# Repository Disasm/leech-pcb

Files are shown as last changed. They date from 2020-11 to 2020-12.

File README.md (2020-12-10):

# Leech

An extension board with iCE40UP5k for the STM32F411 "Black Pill" board.

This project is based on the [icepill] project by [Adam Greig].
Some of the footprints were also taken from the icepill project.

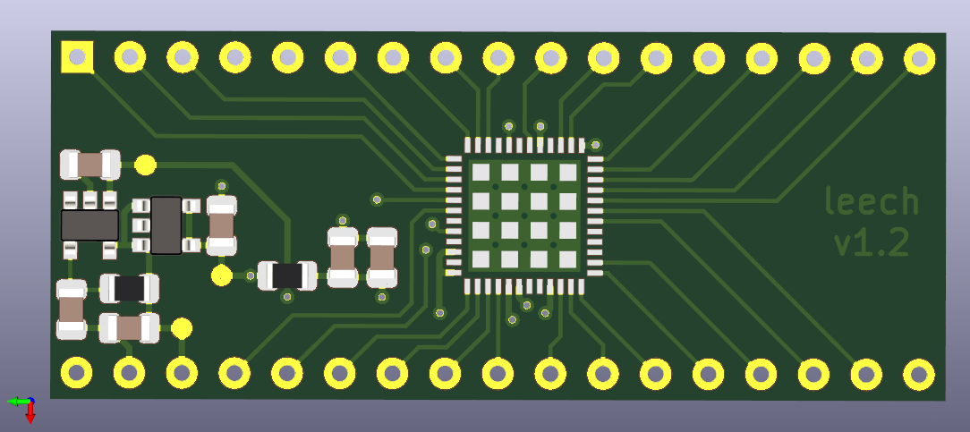
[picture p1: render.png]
PCB render

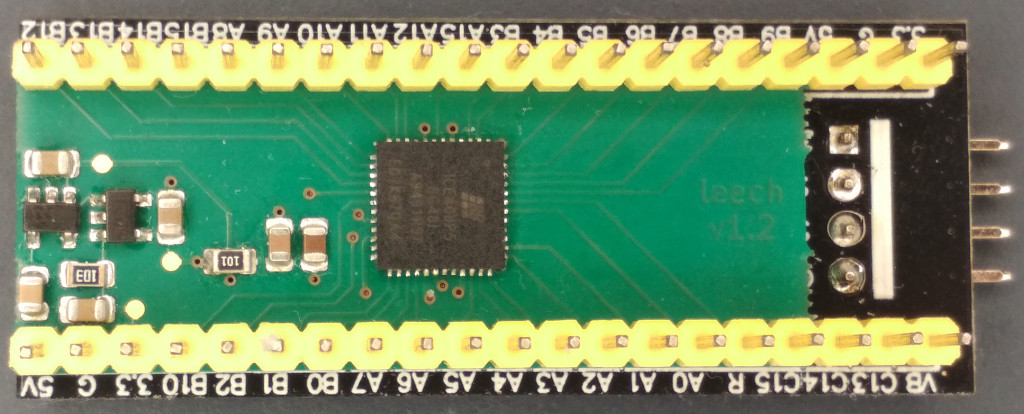
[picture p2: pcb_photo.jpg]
PCB photo


| iCE40  | STM32 | Notes
|---|---|---
| 16 | PB12  | SPI SS
| 15 | PB13  | SPI SCK
| 14 | PB14  | SPI MISO
| 17 | PB15  | SPI MOSI
| 20 | PA8 | Clock for iCE40 provided by MCO
| 13 | PA9 |
| 12 | PA10  |
| 11 | PA11  |
| 10 | PA12  |
| 6 | PA15  |
| 3 | PB3 |
| 2 | PB4 |
| 48 | PB5 |
| 47 | PB6 |
| 46 | PB7 |
| 45 | PB8 |
| 44 | PB9 |
| | |
| 18 | PB10  | Used for IRQ
| CRESET | PB2 | This line is pulled down by the main board
| 25 | PB1 |
| 26 | PB0 |
| 27 | PA7 |
| 28 | PA6 |
| 34 | PA5 |
| 35 | PA4 |
| 36 | PA3 |
| 37 | PA2 |
| 38 | PA1 |
| 42 | PA0 | Connected to a button on the main board
| 43 | RESET |

Firmware and gateware: https://github.com/Disasm/leech-fw

This schematic and PCB design are licensed under the
Creative Commons [CC0 public domain dedication].
It is provided with no warranty.

[icepill]: https://github.com/adamgreig/icepill
[Adam Greig]: https://github.com/adamgreig
[CC0 public domain dedication]: https://creativecommons.org/publicdomain/zero/1.0/

## Revision History

### 1.2: 2020-11-13

* First version.
* Errata:
    * Drill diameter of 2.54mm connector pads is too small.

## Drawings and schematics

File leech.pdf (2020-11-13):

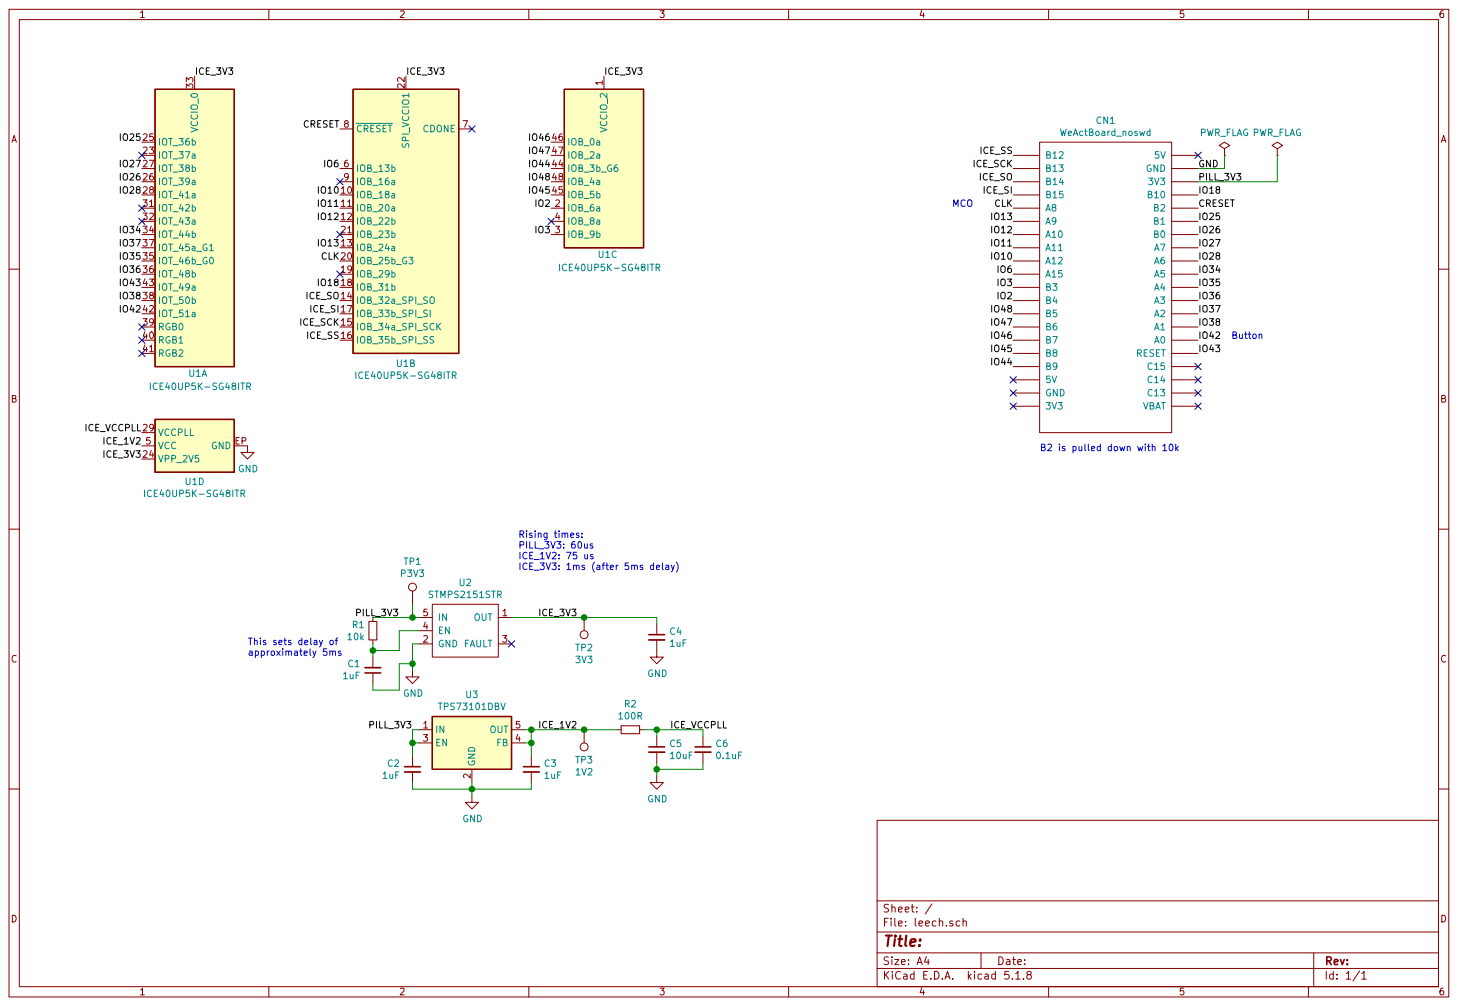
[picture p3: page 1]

IO10 This sets delay of

B2 is pulled down with 10k

Id: 1/1 Title: File: leech.sch Sheet: / C1

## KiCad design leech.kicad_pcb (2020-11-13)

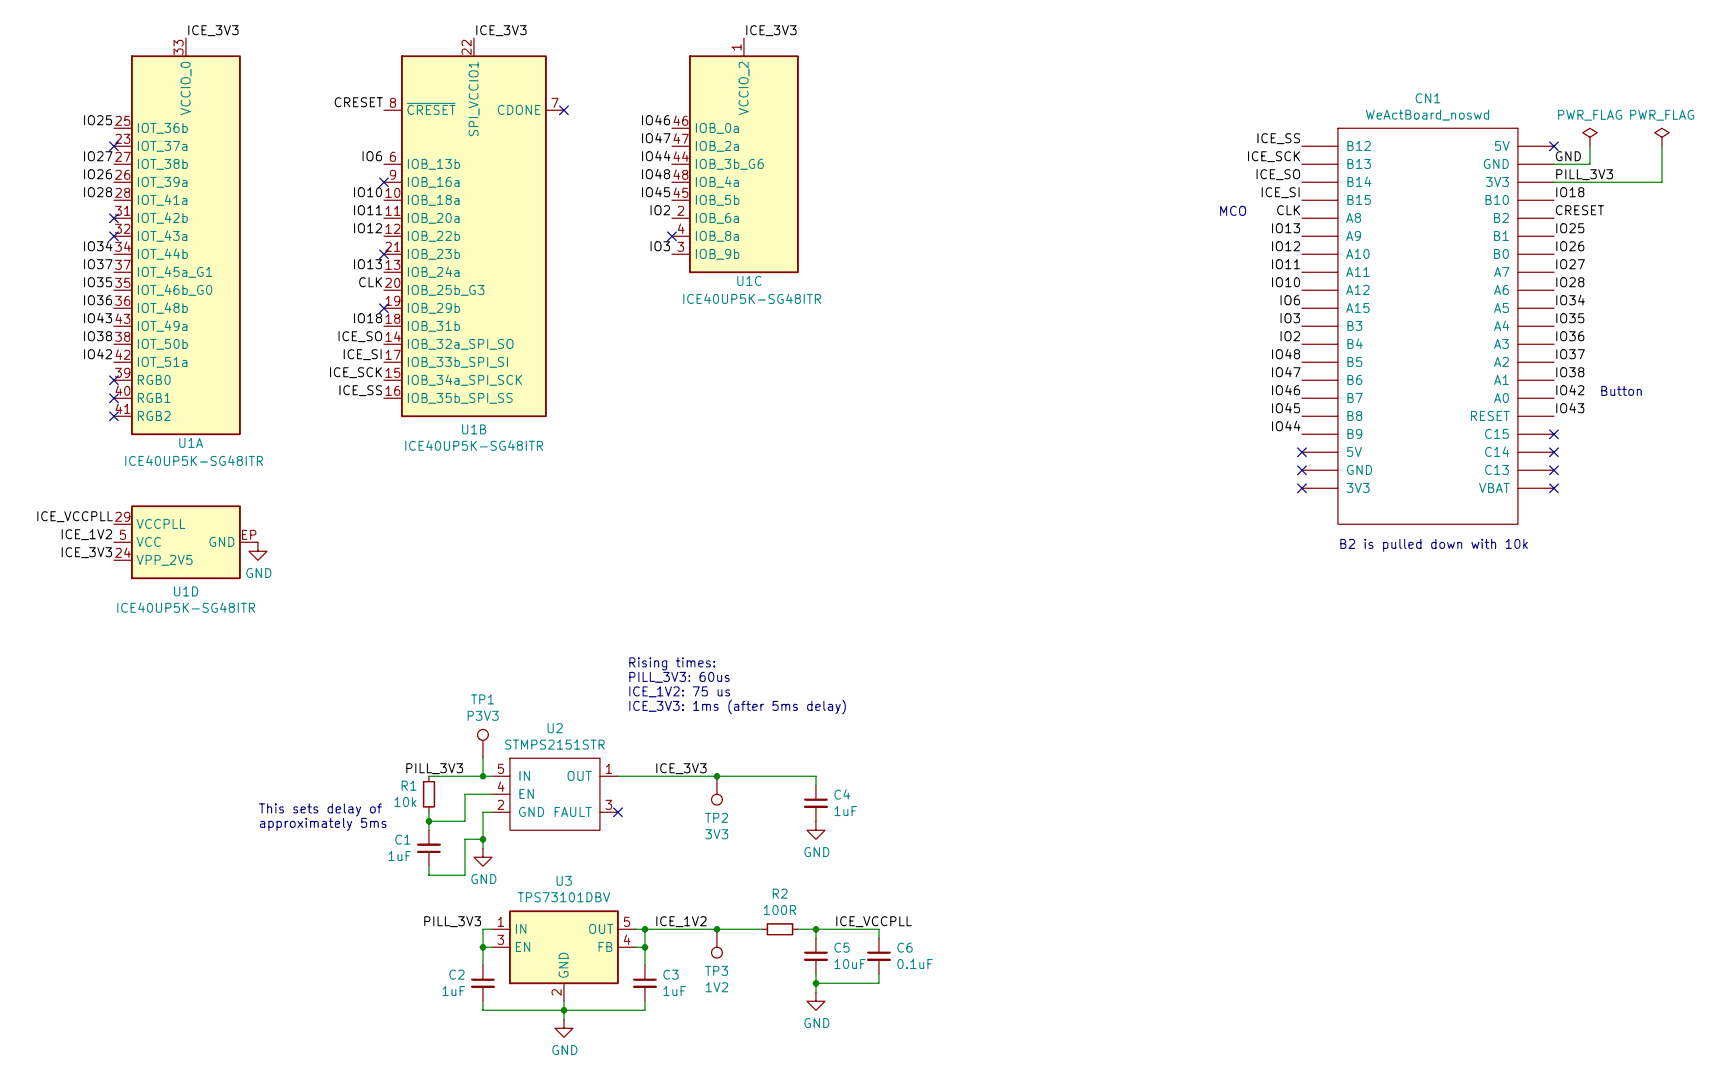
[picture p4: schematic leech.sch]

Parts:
C1, C2, C3, C4: 1uF; C_0805_2012Metric
C5: 10uF; C_0805_2012Metric
C6: 0.1uF; C_0805_2012Metric
CN1: WeActBoard_noswd; WeAct_v3.0_cut
R1: 10k; R_0805_2012Metric
R2: 100R; R_0805_2012Metric
TP1: P3V3; TestPoint_Pad_D1.0mm
TP2: 3V3; TestPoint_Pad_D1.0mm
TP3: 1V2; TestPoint_Pad_D1.0mm
U1: ICE40UP5K-SG48ITR; Lattice-SG48
U2: STMPS2151STR; SOT-23-5
U3: TPS73101DBV; SOT-23-5

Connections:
/CLK: CN1.5 (A8), U1.20 (IOB_25b_G3)
/CRESET: CN1.36 (B2), U1.8 (~CRESET)
/ICE_1V2: C3.1, R2.2, TP3.1, U1.5 (VCC), U1.30 (VCC), U3.4 (FB), U3.5 (OUT)
/ICE_3V3: C4.1, TP2.1, U1.1 (VCCIO_2), U1.22 (SPI_VCCIO1), U1.24 (VPP_2V5), U1.33 (VCCIO_0), U2.1 (OUT)
/ICE_SCK: CN1.2 (B13), U1.15 (IOB_34a_SPI_SCK)
/ICE_SI: CN1.4 (B15), U1.17 (IOB_33b_SPI_SI)
/ICE_SO: CN1.3 (B14), U1.14 (IOB_32a_SPI_SO)
/ICE_SS: CN1.1 (B12), U1.16 (IOB_35b_SPI_SS)
/ICE_VCCPLL: C5.1, C6.1, R2.1, U1.29 (VCCPLL)
/IO2: CN1.12 (B4), U1.2 (IOB_6a)
/IO3: CN1.11 (B3), U1.3 (IOB_9b)
/IO6: CN1.10 (A15), U1.6 (IOB_13b)
/IO10: CN1.9 (A12), U1.10 (IOB_18a)
/IO11: CN1.8 (A11), U1.11 (IOB_20a)
/IO12: CN1.7 (A10), U1.12 (IOB_22b)
/IO13: CN1.6 (A9), U1.13 (IOB_24a)
/IO18: CN1.37 (B10), U1.18 (IOB_31b)
/IO25: CN1.35 (B1), U1.25 (IOT_36b)
/IO26: CN1.34 (B0), U1.26 (IOT_39a)
/IO27: CN1.33 (A7), U1.27 (IOT_38b)
/IO28: CN1.32 (A6), U1.28 (IOT_41a)
/IO34: CN1.31 (A5), U1.34 (IOT_44b)
/IO35: CN1.30 (A4), U1.35 (IOT_46b_G0)
/IO36: CN1.29 (A3), U1.36 (IOT_48b)
/IO37: CN1.28 (A2), U1.37 (IOT_45a_G1)
/IO38: CN1.27 (A1), U1.38 (IOT_50b)
/IO42: CN1.26 (A0), U1.42 (IOT_51a)
/IO43: CN1.25 (RESET), U1.43 (IOT_49a)
/IO44: CN1.17 (B9), U1.44 (IOB_3b_G6)
/IO45: CN1.16 (B8), U1.45 (IOB_5b)
/IO46: CN1.15 (B7), U1.46 (IOB_0a)
/IO47: CN1.14 (B6), U1.47 (IOB_2a)
/IO48: CN1.13 (B5), U1.48 (IOB_4a)
/PILL_3V3: C2.1, CN1.38 (3V3), R1.1, TP1.1, U2.5 (IN), U3.1 (IN), U3.3 (EN)
GND: C1.1, C2.2, C3.2, C4.2, C5.2, C6.2, CN1.39 (GND), U1.EP (GND), U2.2 (GND), U3.2 (GND)
unnamed: C1.2, R1.2, U2.4 (EN)

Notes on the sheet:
B2 is pulled down with 10k
Button
MCO
This sets delay of approximately 5ms
Rising times: PILL_3V3: 60us ICE_1V2: 75 us ICE_3V3: 1ms (after 5ms delay)

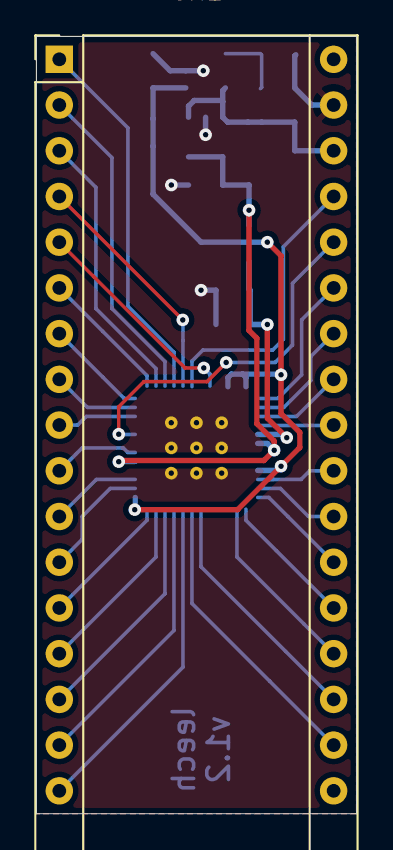
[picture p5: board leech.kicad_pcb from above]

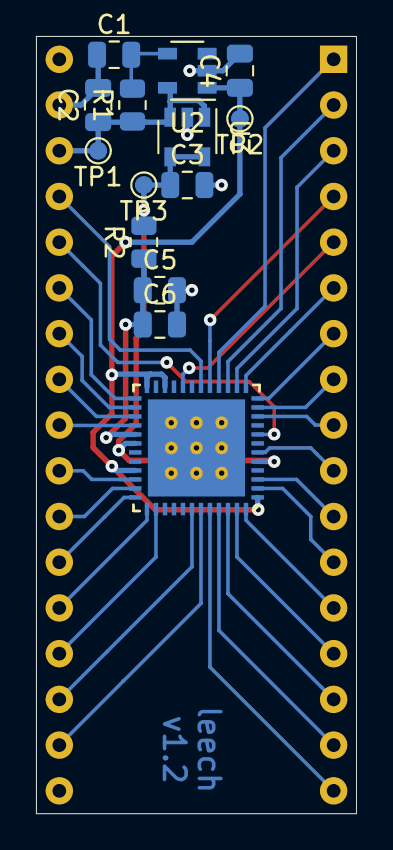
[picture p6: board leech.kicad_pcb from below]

Board: 2 copper layers, 17.8 x 43.2 mm, 15 parts (14 on the bottom side), 36 nets.

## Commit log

2020-11-12 Add board schematics and layout
    [leech.kicad_pcb, leech.sch]
2020-11-12 Set solder mask params to zero to fix warning
    [leech.kicad_pcb]
2020-11-12 Prepare for Gerber generation
    [leech.kicad_pcb]
2020-11-12 Generate gerbers
    [leech.kicad_pcb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]
2020-11-13 Revert "Set solder mask params to zero to fix warning"
    This reverts commit 59b1d9f25f2c3b17ac02e019903f67e575fe32d2.
    [leech.kicad_pcb]
2020-11-13 Update the iCE40 footprint to prevent 'half-covered vias' warning
    [leech.kicad_pcb]
2020-11-13 Update board version to 1.2, regenerate gerbers
    [leech.kicad_pcb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]
2020-11-13 Add schematics pdf
